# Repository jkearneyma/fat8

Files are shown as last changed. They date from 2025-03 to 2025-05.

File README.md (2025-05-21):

# fat8
A physically tiny, but fat in capability Intel 8008 SBC.  Smaller than a business card although quite a bit thicker.

This is not pure vintage design, rather its intent is to keep the flavor of one by pairing a real 8008 CPU with its maximum RAM footprint as a vehicle for running larger software like Scelbi's SCELBAL and GALAXY, emulators, and other fun projects.

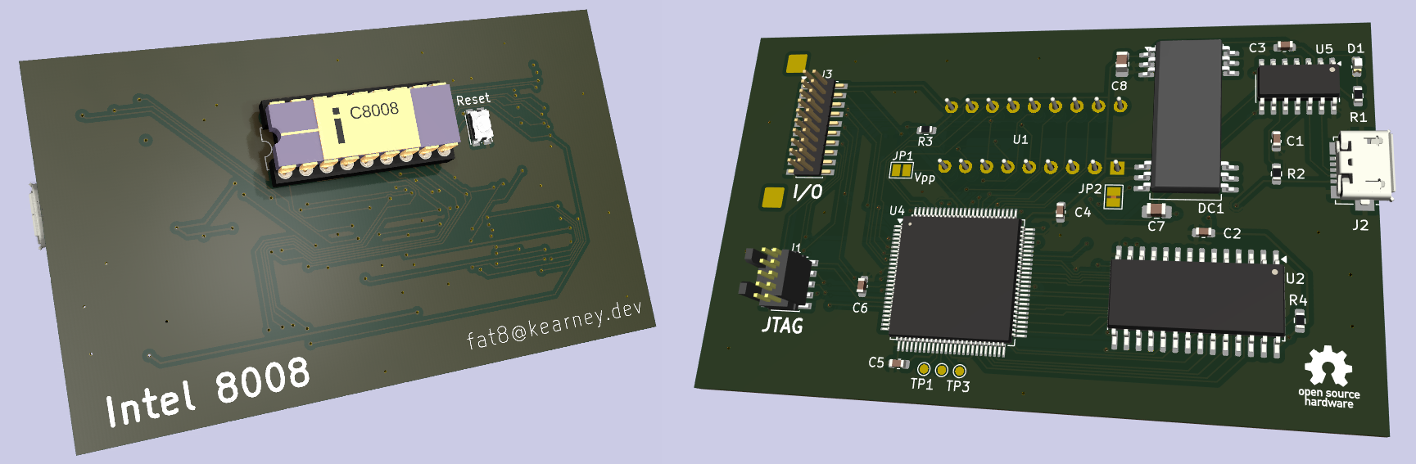
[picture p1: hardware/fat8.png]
render of fat8


- 8008 CPU running at ~ 50K instructions per second (500 KHz clock).
- 32KB of nonvolatile RAM (16KB addressable at a time)
- Connects to a PC as a USB serial terminal
- 3 input and 3 output ports available on an expansion connector
- Machine-level monitor program
- Prebuilt images for SCELBAL and GALAXY

[Hardware page](hardware/)\
[Software page](software/)\
[Tools page](tools/)

## Operation

1. Connect to USB
2. Open serial terminal program, for example minicom
3. Select the new port (probably /dev/ttyACM0) and set for to 2400 8N1
4. Press 'Reset' button
5. You should see the monitor prompt.  Press '?' for a list of commands.

## Licenses

Software and tools : [BSD-3-Clause](LICENSE.BSD-3-Clause)\
Hardware and CPLD programming : [CERN Open Hardware Licence Version 2 - Weakly Reciprocal](LICENSE.CERN-OHL-W-2.0)

SPDX-License-Identifier: BSD-3-Clause\
SPDX-License-Identifier: CERN Open Hardware Licence Version 2 - Weakly Reciprocal

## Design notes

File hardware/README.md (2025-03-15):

# fat8 Hardware

The hardware is physically quite minimal but is still "discrete" in the sense that the 8008 CPU is supported by gate-level logic and an actual memory IC, not a microcontroller or FPGA pretending to be logic or memory.  The highest integration chip is actually the USB interface, which is actually an embedded PIC processor.  The only thing that device does is provide a clock signal and a TTL serial connection, however.

The memory IC is a ferro-magnetic RAM (FRAM), which is nonvolatile yet fast so it serves as both RAM and ROM in the design.

The "gate-level logic" is built in a programmable logic device.  It's relatively small (64 logic blocks), but that's big enough to implement the ~25 latches and 40+ gates needed to do all the state decoding, bus demultiplexing and other functions necessary.  The device is the (ex)Atmel ATF1504 CPLD.  It is old enough to have 5V I/O but new enough to be in-circuit (re)programmable using JTAG. Futhermore, it supports JTAG boundary scan, which allows us to download data into the FRAM by wiggling the I/O lines connected to it, which solves the bootstrap problem.

The [cpld/](../cpld/) folder contains the logic description for the CPLD, and the [tools/](../tools/) folder has the utilities needed to program the various devices.

The 8008 is a PMOS design, and requires a -9V supply (actually it requires a 14V supply and its logic signals are 9V-14V).  A small isolated DC-DC converter takes care of this.

This folder contains the schematic and board (Work In Progress) created in Kicad 9.

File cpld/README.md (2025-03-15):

# CPLD logic

Note: this project is built under Linux, except for the vintage CPLD tools which were published on Windows.  I'm running the Windows programs in a Gnome Boxes VM with Windows 7 installed, but bare-metal Windows or any other VM manager will work.  It is probably possible to run the Windows tools under WINE but that isn't tested or documented by me.  

The CPLD implements all the random logic for fat8.  This is primarily fundamental 8008 stuff like clock generation, state decoding, address demultiplexing, and I/O decoding.  In addition, it exposes the USB Rx/Tx to the CPU data bus as an I/O port, and implements an FRAM write protect register with 2KB resolution as another I/O register.

If you're not changing anything, you don't need to do anything below; the output files are provided.

## fat8.pld

The complete implementation.  The CPLD is the AFT1504AS, which is one of the few 5V CPLDs still available.  Atmel built it, and was acquired later by MicroChip: https://www.microchip.com/en-us/product/ATF1504AS

## fat8.jed

The output of the logic compiler in JEDEC format.

The logic compiler used is WinCUPL.  It may be downloaded from https://www.microchip.com/en-us/products/fpgas-and-plds/spld-cplds/pld-design-resources

After compilation of fat8.pld, various output files are produced, the most important one being fat8.jed and secondly fat8.fit which documents the resulting hardware.

## fat8.svf

If one happens to have a ATDH1150USB programming cable, the fat8.jed file can be directly downloaded using ATMISP from the above web page.  You will need an adapter from one of its connectors (see page 6 of [its user manual](https://ww1.microchip.com/downloads/en/DeviceDoc/Atmel-8909-CPLD-ATDH1150USB-ATF15-JTAG-ISP-Download-Cable-UserGuide.pdf)) to the more common [Arm Coresight JTAG](https://developer.arm.com/documentation/101761/1-0/Target-interface-connectors/CoreSight-10-connector) connector, which is 10 pins on 0.05" spacing.

If not, it can be converted into a .svf file that openocd or other JTAG tools support, using ATMISP.

Create a new project in ATMISP with one device, then select a device of ATF1504AS, JTAG instruction of Program/Verify, and the fat8.jed file. After clicking OK, check the Write SVF File box and enter fat8.svf into the destination, then click the Run button.

## Using openocd and one of its supported JTAG probes

Make sure that you have the appropriate JTAG connector or adapter for your device to a [Arm Coresight JTAG](https://developer.arm.com/documentation/101761/1-0/Target-interface-connectors/CoreSight-10-connector) connector.  Your programmer must be capable of 5V operation.

Scripts are provided under [tools](../tools/) to play the SVF file.  Typical usage would be:
````
openocd -f interface/ftdi/olimex-arm-usb-ocd-h.cfg -f ../tools/atf1504_program.tcl
````
If you have an Olimex ARM-USB-TINY-H with ARM-JTAG-20-10 adapter.

Any JTAG adapter + software capable of 5V operation and playing an SVF file should work, for example there are numerous inexpensive designs using FTDI chips.

## Extreme measures

It's apparently possible that the CPLD is in a state where it won't accept programming without extra work.

First, according to the some manufacturer notes, it may be necessary to stop input clocks during programming.  I've not seen this, but there is provision on the board to cut the clock trace at JP2 (and later jumper it).

Second, for some devices, [it may be necessary to apply 12V to the OE1 pin to enable programming](https://www.hackup.net/2020/01/erasing-and-programming-the-atf1504-cpld/).  There is a cuttable jumper at JP1 for this purpose.

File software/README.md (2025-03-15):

# Software

This project is built under Linux, except for the vintage CPLD tools which were published on Windows.  It is probably possible to run the Windows tools under WINE, or the assembler and Python tools on Windows, but those paths are not documented here.

## Tools required

* [Macroassembler AS](http://john.ccac.rwth-aachen.de:8000/as/), which can be more conveniently built on Linux using [this repository](https://github.com/Macroassembler-AS/asl-releases)
* Python 3 with intelhex, bitstring, and hid modules installed
* Software in [tools/](../tools/) directory of this project

## monitor.asm

Simple terminal-oriented monitor.  No real debugging ability, just
display and modification of bytes in memory, start execution
somewhere, and do byte I/O.

| Commands: | |
| :---- | :---- |
| P aa:aaa | print 8 bytes, Enter/Esc |
| E aa:aaa | enter bytes until Esc |
| J aa:aaa | jump to address |
| I p | input from port p |
| O p ddd | output to port 1p |
| S | start SCELBAL (jump to 06:000) |
| :<data> | Intel hex loader (Work In Progress) |

Note that memory addresses in the monitor are in "split
octal" form.  It's a bit different from hexadecimal
(literally) because the high-order address byte has 2
digits and the low-order byte has 2 2/3 digits. '2/3'
of a digit means it only ranges from 0 to 3.

FRAM Memory is non-volatile, thus there is no RAM or ROM
distinction.  However there are some memory controls:

### Write Protection
I/O port 1 is a byte register where each bit protects a 2KB area; the least
significant bit protects the first 2KB and so on.

### Memory Banks
The FRAM is 32KB but the 8008 can address only 16KB.  The USB interface
stores two configuration bits in its nonvolatile settings that switch
each 8KB half between two alternates.  The usb-config.py program has
command-line options to set these.

Because the monitor + SCELBAL image is closer to 10KB, these are best used
in tandem to switch between two complete memory images.

### Memory Map

| Write protected at power-up: |
| :----- |
| 00:000-05:377 : Monitor |
| 06:000-37:377 : SCELBAL code |

| Writable at power-up: |
| :---- |
| 40:000-77:377 : SCELBAL data and user program |

A machine-code program may be loaded in high memory and would only
interfere with SCELBAL if a very large SCELBAL program is loaded.

If a larger program area is needed, SCELBAL can be overwritten by
disabling the memory protection for all but the first 2KB containing
the monitor ('O 1 001') and then from 08:000 to 77:377 is available.

### Monitor-supplied facilities
These use the 1-byte call instruction RST *n*:

| RST instruction | Action | Uses |
| :---- | :---- | :---- |
| RST 0 | Enter monitor | *n/a* |
| RST 1 | Print zero-terminated string | ABHL |
| RST 3 | Print char in A | B |
| RST 4 | Read character to A | AB |
| RST 5 | Delay 14B+12 cycles (incl RST) | B |
| RST 6 | Reserved for future definition | |

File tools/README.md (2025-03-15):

# Tools for programming and testing fat8

## usb-config.py

Programs the MCP2221A for its role on fat8:
- provides 3 MHz clock
- provides 2 sticky configuration bits to control the mapping of the FRAM (32KB) to the CPU address space (16KB)

```
# you will need to unload and possibly blacklist this kernel module
# in newer Linux versions because it sets up the USB interface for I2C:
sudo rmmod hid_mcp2221
# Then configure the device, unplug and plug:
sudo ./usb-config.py [-cfg0] [-cfg1]
```

## emulator.py

Software emulation of the board - reads a .hex file and executes it.  Character I/O is intercepted, and write-protects (port 1/11) are emulated.

## atf1504_program.tcl

openocd script to program the CPLD using JTAG by uploading cpld/fat8.svf.  Sample command line:
openocd -f <jtag adapter>.cfg -f atf1504_program.tcl

## fram-programmer.py

Translate an Intel hex file to JTAG a boundary scan command file which writes the contents into the FRAM by wiggling the CPLD's pins.  Used in software/ to prepare code for upload

## fm1808_program.tcl and fm1808_verify.tcl

openocd scripts to execute software/image.svf and software/verify.svf

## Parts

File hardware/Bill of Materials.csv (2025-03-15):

Reference | Qty | Description | Nominal Part | Package
U1 | 1 | CPU | Intel D8008 / C8008 | DIP-18
U2 | 1 | FRAM | Infineon FM1808B-SG | SOIC-28
U4 | 1 | CPLD | Microchip ATF1504AS-10AU100 | TQFP-100
U5 | 1 | USB | Microchip MCP2221A-I/SL | SOIC-14
DC1 | 1 | 5V-9V isolated DC-DC conv | TI DCP020509U | SOIC-28
D1 | 1 | LED | Würth 150060BS55040 | SMD 0603
SW1 | 1 | Tact button | C&K KMR241GLFS
R1 | 1 | 1.0K | KOA SG731JTTD102K | SMD 0603
R2,R3,R4 | 3 | 10K | KOA SG731JTTD103K | SMD 0603
C1,C2,C3,C4,C5,C6 | 6 | 0.1 µF | Taiyo Yuden LMF107B7104MAHT | SMD 0603
C7 | 1 | 1.0 µF | Taiyo Yuden LMK212B7105KD-T | SMD 0805
C8 | 1 | 2.2 µF low ESR | Taiyo Yuden LMK212B7225MGHT | SMD 0805
J1 | 1 | Header 2x5 1.27mm | Amphenol 10166143-00010C1LF
J2 | 1 | USB micro-B female | Molex 0473460001
J3 | 1 | Header 2x10 1.27mm | Amphenol 10166143-00020C1LF
J4 | 1 | DIP socket | On Shore Tech SA183040 | DIP-18

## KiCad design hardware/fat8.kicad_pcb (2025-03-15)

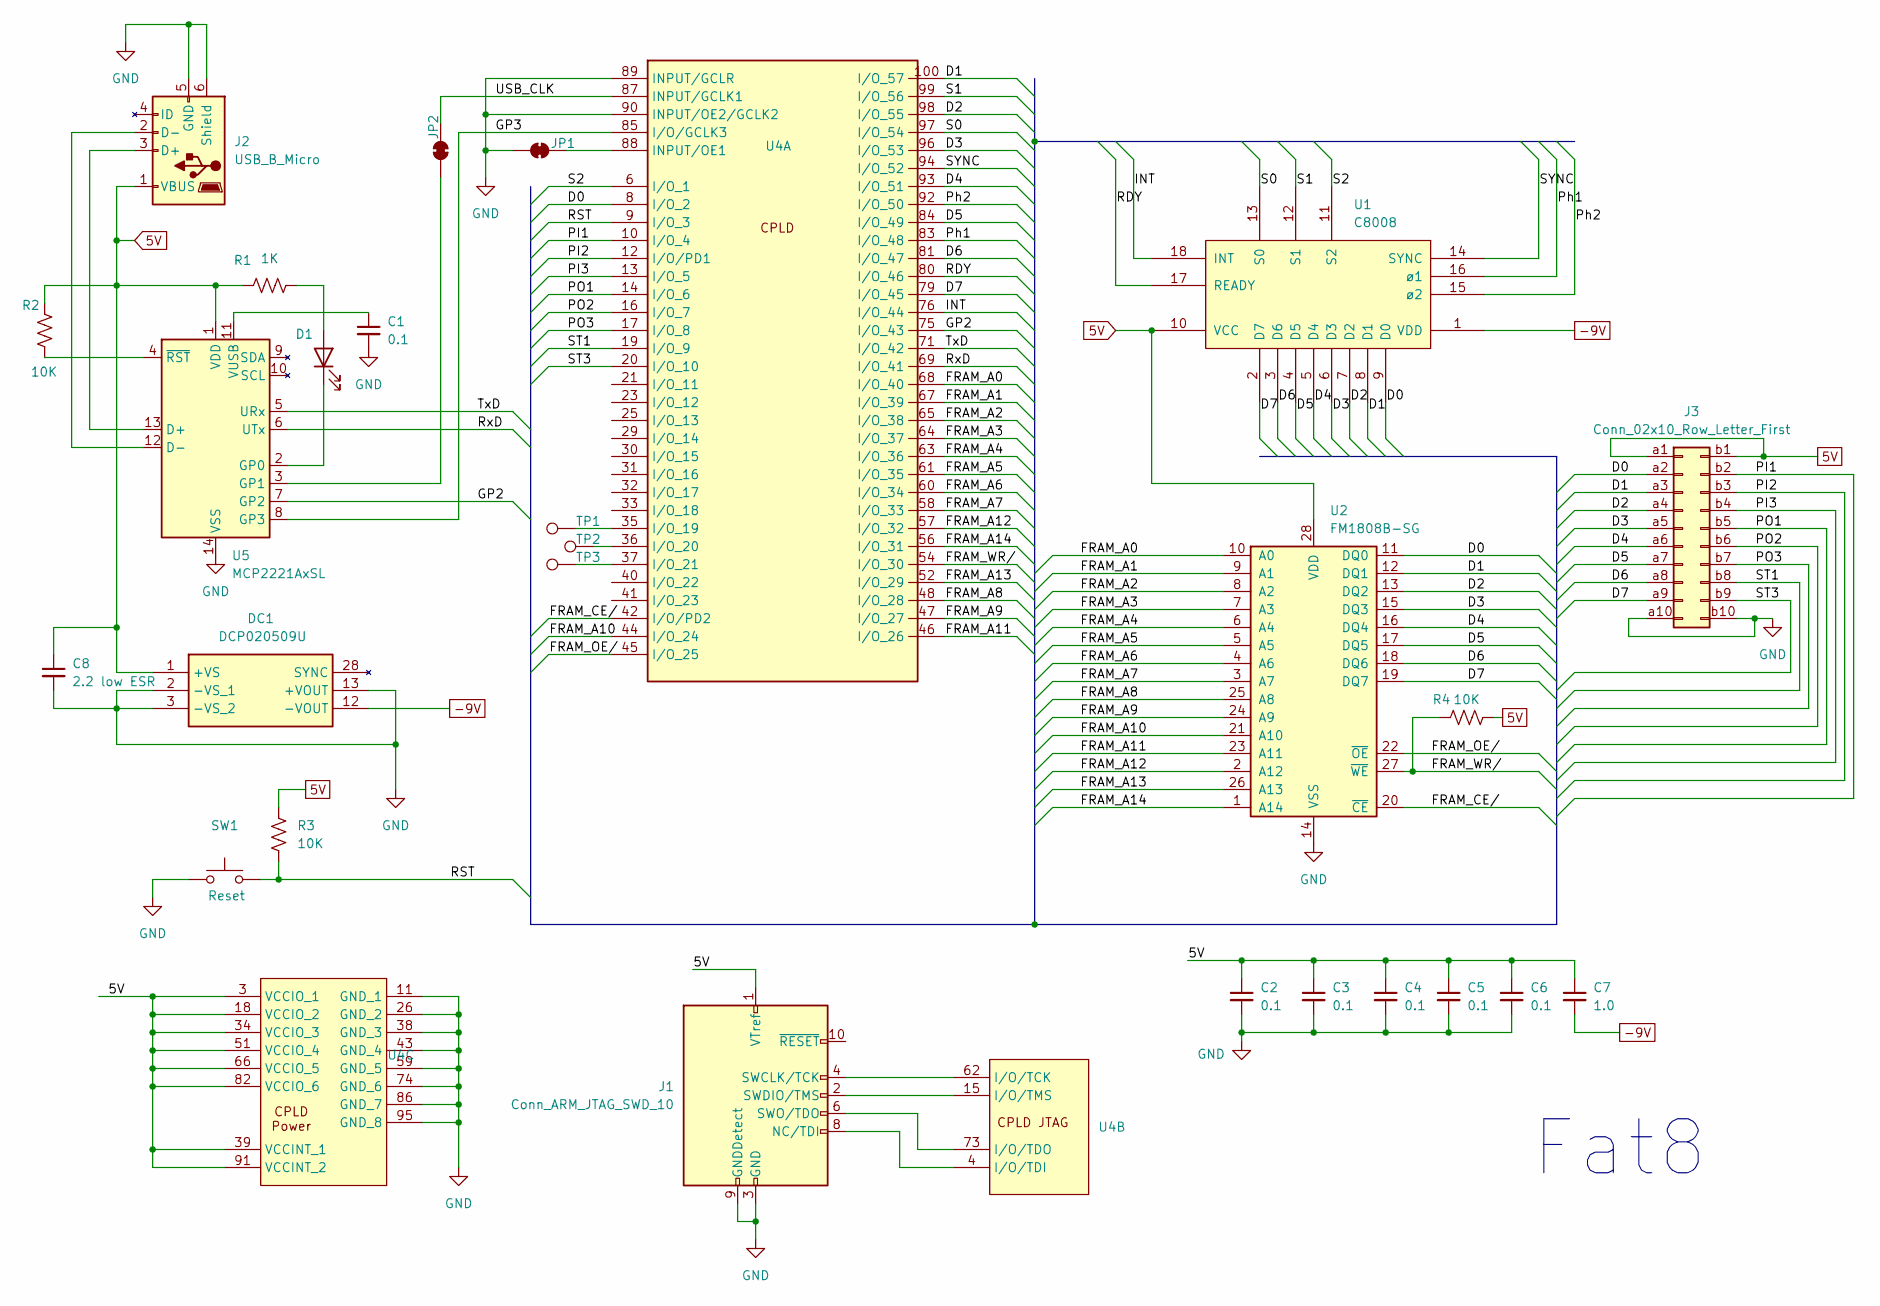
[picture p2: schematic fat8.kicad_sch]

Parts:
C1, C2, C3, C4, C5, C6: 0.1; C_0603_1608Metric
C7: 1.0; C_0805_2012Metric_Pad1.18x1.45mm_HandSolder
C8: 2.2 low ESR; C_0805_2012Metric_Pad1.18x1.45mm_HandSolder
D1: LED; C_0603_1608Metric
DC1: DCP020509U; SOIC-28W_7.5x18.7mm_P1.27mm; Mouser Part Number 595-DCP020509U
J1: Conn_ARM_JTAG_SWD_10; PinHeader_2x05_P1.27mm_Vertical_SMD
J2: USB_B_Micro; USB_Micro-B_Molex_47346-0001
J3: Conn_02x10_Row_Letter_First; PinHeader_2x10_P1.27mm_Vertical_SMD
JP1, JP2: SolderJumper_2_Bridged; SolderJumper-2_P1.3mm_Bridged_Pad1.0x1.5mm
R1: 1K; R_0603_1608Metric
R2, R3, R4: 10K; R_0603_1608Metric
SW1: KMR241GLFS; SW_Push_1P1T_NO_CK_KMR2
TP1, TP2, TP3: TestPoint; TestPoint_Pad_D1.0mm
U1: C8008; DIP-18_W7.62mm_SMDSocket_SmallPads
U2: FM1808B-SG; SOIC-28W_7.5x17.9mm_P1.27mm
U4: ATF1504ASL-25AU100; VQFP-100_14x14mm_P0.5mm; Mouser Part Number 556-AF1504ASL25AU100
U5: MCP2221AxSL; SOIC-14_3.9x8.7mm_P1.27mm

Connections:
5V: C2.1, C3.1, C4.1, C5.1, C6.1, C7.1, C8.1, DC1.1 (+VS), J1.1 (VTref), J2.1 (VBUS), J3.a1, J3.b1, R1.1, R2.2, R3.1, R4.2, U1.10 (VCC), U2.28 (VDD), U4.3 (VCCIO_1), U4.18 (VCCIO_2), U4.34 (VCCIO_3), U4.39 (VCCINT_1), U4.51 (VCCIO_4), U4.66 (VCCIO_5), U4.82 (VCCIO_6), U4.91 (VCCINT_2), U5.1 (VDD)
-9V: C7.2, DC1.12 (-VOUT), U1.1 (VDD)
/D0: J3.a2, U1.9 (D0), U2.11 (DQ0), U4.8 (I/O_2)
/D1: J3.a3, U1.8 (D1), U2.12 (DQ1), U4.100 (I/O_57)
/D2: J3.a4, U1.7 (D2), U2.13 (DQ2), U4.98 (I/O_55)
/D3: J3.a5, U1.6 (D3), U2.15 (DQ3), U4.96 (I/O_53)
/D4: J3.a6, U1.5 (D4), U2.16 (DQ4), U4.93 (I/O_51)
/D5: J3.a7, U1.4 (D5), U2.17 (DQ5), U4.84 (I/O_49)
/D6: J3.a8, U1.3 (D6), U2.18 (DQ6), U4.81 (I/O_47)
/D7: J3.a9, U1.2 (D7), U2.19 (DQ7), U4.79 (I/O_45)
/FRAM_A0: U2.10 (A0), U4.68 (I/O_40)
/FRAM_A1: U2.9 (A1), U4.67 (I/O_39)
/FRAM_A2: U2.8 (A2), U4.65 (I/O_38)
/FRAM_A3: U2.7 (A3), U4.64 (I/O_37)
/FRAM_A4: U2.6 (A4), U4.63 (I/O_36)
/FRAM_A5: U2.5 (A5), U4.61 (I/O_35)
/FRAM_A6: U2.4 (A6), U4.60 (I/O_34)
/FRAM_A7: U2.3 (A7), U4.58 (I/O_33)
/FRAM_A8: U2.25 (A8), U4.48 (I/O_28)
/FRAM_A9: U2.24 (A9), U4.47 (I/O_27)
/FRAM_A10: U2.21 (A10), U4.44 (I/O_24)
/FRAM_A11: U2.23 (A11), U4.46 (I/O_26)
/FRAM_A12: U2.2 (A12), U4.57 (I/O_32)
/FRAM_A13: U2.26 (A13), U4.52 (I/O_29)
/FRAM_A14: U2.1 (A14), U4.56 (I/O_31)
/FRAM_CE/: U2.20 (~CE), U4.42 (I/O/PD2)
/FRAM_OE/: U2.22 (~OE), U4.45 (I/O_25)
/FRAM_WR/: R4.1, U2.27 (~WE), U4.54 (I/O_30)
/GP2: U4.75 (I/O_43), U5.7 (GP2)
/GP3: U4.85 (I/O/GCLK3), U5.8 (GP3)
/INT: U1.18 (INT), U4.76 (I/O_44)
/PI1: J3.b2, U4.10 (I/O_4)
/PI2: J3.b3, U4.12 (I/O/PD1)
/PI3: J3.b4, U4.13 (I/O_5)
/PO1: J3.b5, U4.14 (I/O_6)
/PO2: J3.b6, U4.16 (I/O_7)
/PO3: J3.b7, U4.17 (I/O_8)
/Ph1: U1.16 (ø1), U4.83 (I/O_48)
/Ph2: U1.15 (ø2), U4.92 (I/O_50)
/RDY: U1.17 (READY), U4.80 (I/O_46)
/RST: R3.2, SW1.2, U4.9 (I/O_3)
/RxD: U4.69 (I/O_41), U5.6 (UTx)
/S0: U1.13 (S0), U4.97 (I/O_54)
/S1: U1.12 (S1), U4.99 (I/O_56)
/S2: U1.11 (S2), U4.6 (I/O_1)
/ST1: J3.b8, U4.19 (I/O_9)
/ST3: J3.b9, U4.20 (I/O_10)
/SYNC: U1.14 (SYNC), U4.94 (I/O_52)
/TxD: U4.71 (I/O_42), U5.5 (URx)
/USB_CLK: JP2.2 (B), U4.87 (INPUT/GCLK1)
GND: C1.2, C2.2, C3.2, C4.2, C5.2, C6.2, C8.2, DC1.2 (-VS_1), DC1.3 (-VS_2), DC1.13 (+VOUT), J1.3 (GND), J1.5 (GND), J1.9 (GNDDetect), J2.5 (GND), J2.6 (Shield), J3.a10, J3.b10, JP1.1 (A), SW1.1, U2.14 (VSS), U4.11 (GND_1), U4.26 (GND_2), U4.38 (GND_3), U4.43 (GND_4), U4.59 (GND_5), U4.74 (GND_6), U4.86 (GND_7), U4.89 (INPUT/GCLR), U4.90 (INPUT/OE2/GCLK2), U4.95 (GND_8), U5.14 (VSS)
unnamed: D1.2 (A), R1.2
unnamed: D1.1 (K), U5.2 (GP0)
unnamed: J1.8 (NC/TDI), U4.4 (I/O/TDI)
unnamed: J1.4 (SWCLK/TCK), U4.62 (I/O/TCK)
unnamed: J1.2 (SWDIO/TMS), U4.15 (I/O/TMS)
unnamed: J1.6 (SWO/TDO), U4.73 (I/O/TDO)
unnamed: J2.3 (D+), U5.13 (D+)
unnamed: J2.2 (D-), U5.12 (D-)
unnamed: JP1.2 (B), U4.88 (INPUT/OE1)
unnamed: JP2.1 (A), U5.3 (GP1)
unnamed: TP1.1, U4.35 (I/O_19)
unnamed: TP2.1, U4.36 (I/O_20)
unnamed: TP3.1, U4.37 (I/O_21)
unnamed: C1.1, U5.11 (VUSB)
unnamed: R2.1, U5.4 (~RST)

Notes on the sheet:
Fat8

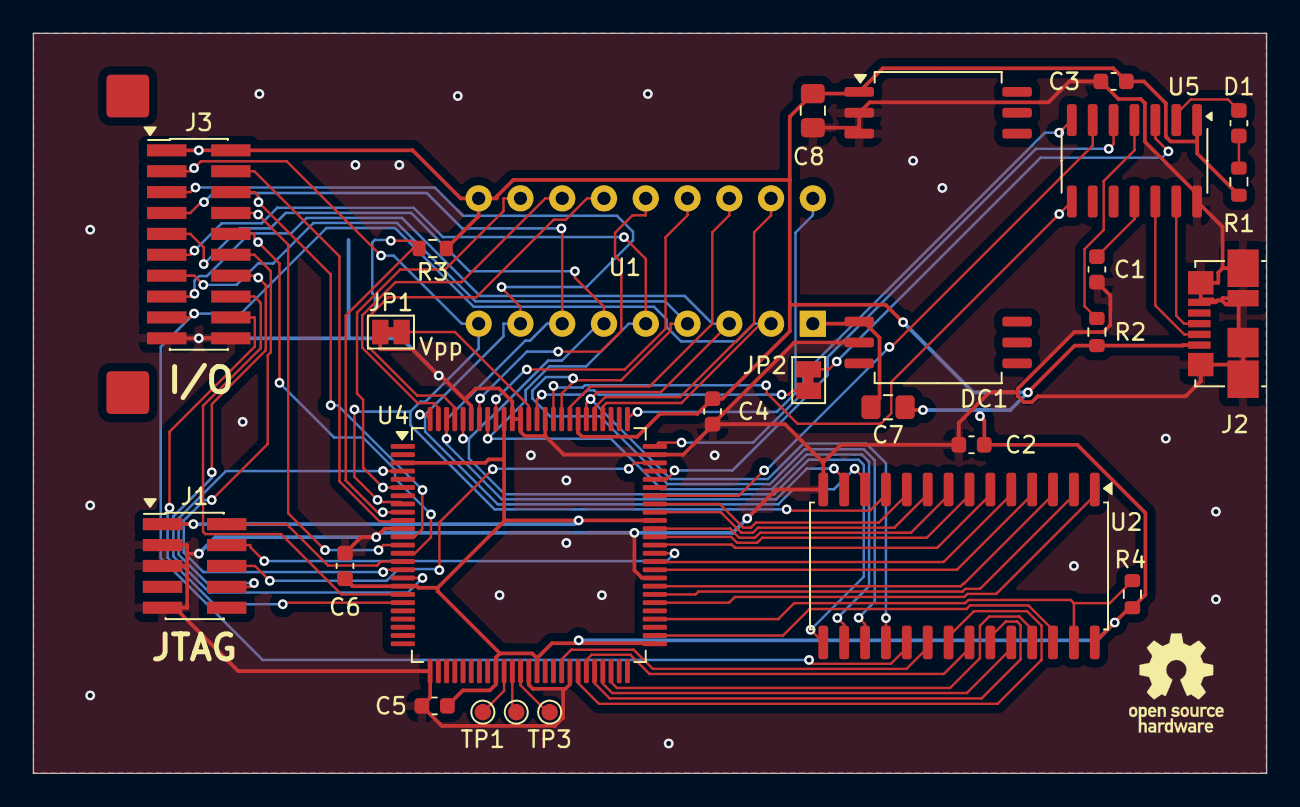
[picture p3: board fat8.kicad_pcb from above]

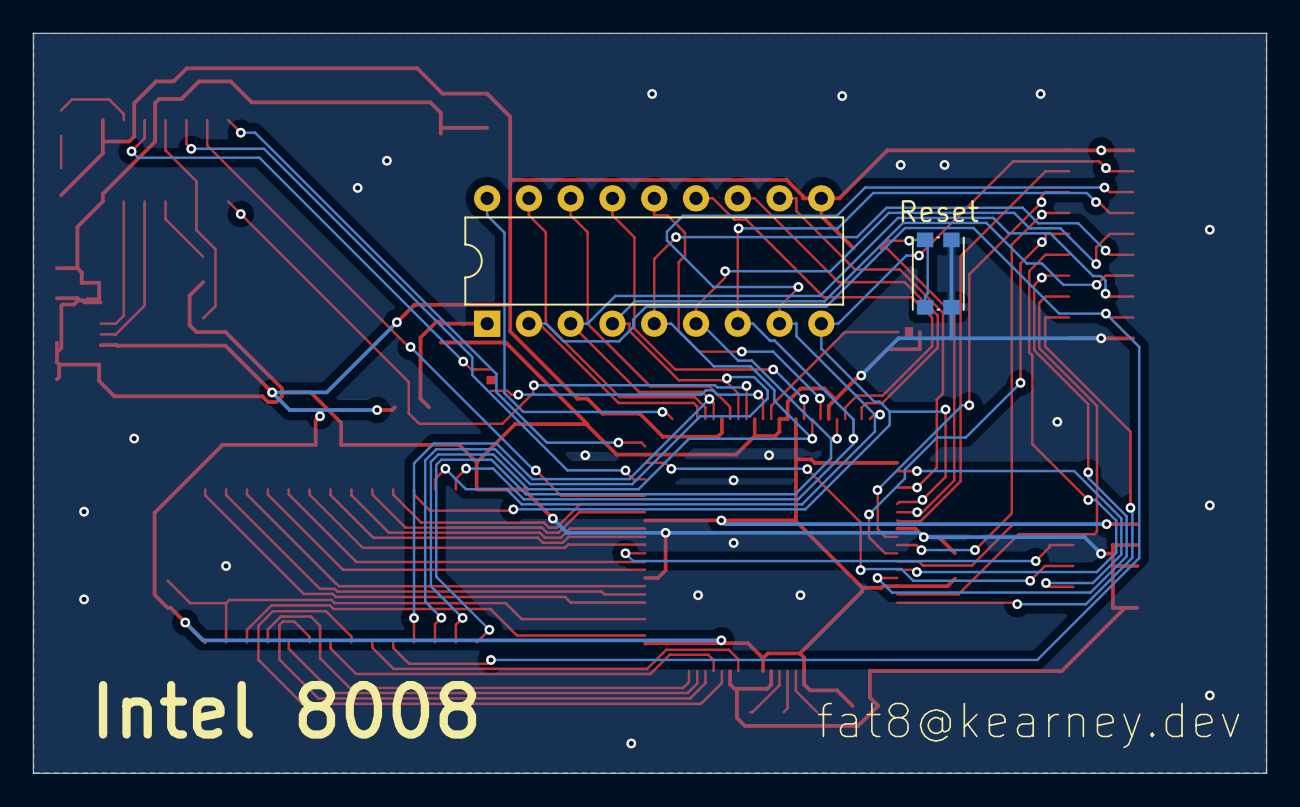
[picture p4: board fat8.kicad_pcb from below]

Board: 2 copper layers, 75.0 x 45.0 mm, 32 parts (2 on the bottom side), 66 nets.

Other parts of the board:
MP1, MP2: MountingHole_2.2mm_M2_DIN965_Pad_TopOnly
SYM1: OSHW-Logo_5.7x6mm_SilkScreen
SYM2, SYM3: c0931fb2-f178-4981-b6e2-5fc50c4e7324
